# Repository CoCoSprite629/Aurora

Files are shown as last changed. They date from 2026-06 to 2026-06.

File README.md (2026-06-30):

# 🌌 Aurora

> 基于 ESP32 的桌面智能天气终端 ｜ IoT Desktop Smart Weather Display

**Aurora**（曙光女神）是一款基于 **ESP32** 的桌面智能物联网终端。通过 WiFi 联网获取实时天气、未来预报、NTP 网络时间与节日信息，将数据呈现在 **HMI 串口触摸屏**上，同时以 **WS2812B 可编程 LED** 的呼吸灯效反馈系统状态。整机配备 3D 打印外壳，适合作为桌面摆件、电子手工作品或物联网学习项目。

---






---

## 功能特性

- 🌤️ **实时天气显示** — 调用高德天气 API，获取当前温度、湿度、风力及天气状况
- 📅 **未来三日预报** — 滚动展示未来三天的日间/夜间天气与温度
- ⏰ **NTP 网络时间** — 自动同步微软 NTP 服务器（`time.windows.com`），无需手动校准
- 🎉 **节日提醒** — 每日自动查询当天节日/纪念日，展示在屏幕底部
- 💡 **智能 LED 反馈** — 根据 WiFi 状态与温度范围变换颜色与呼吸节奏
- 📟 **HMI 串口屏交互** — 通过 Serial2 自定义协议驱动触摸屏，支持配网输入
- 📊 **双进度条** — 一天已过进度 + 自定义倒计时进度条
- 🧵 **FreeRTOS 多任务调度** — 3 个任务跨 Core 0 / Core 1 高效协同
- 🖨️ **3D 打印外壳** — 提供完整 STL 模型，可自行打印装配

---

## 硬件清单

| 组件 | 型号/规格 | 数量 | 说明 |
|---|---|:----:|---|
| 主控 | ESP32 DOIT DevKit V1 | 1 | WiFi + 蓝牙双模 |
| LED | WS2812B 可编程灯珠 | 1 | 状态指示灯，GRB 色彩排列 |
| 触摸屏 | 陶晶驰 (TJC) HMI 串口屏 | 1 | 用户交互界面 |
| 电源 | 5V / Micro-USB | 1 | 供电 |
| 检测脚 | 外部传感器 / 按键 (可选) | 1 | GPIO 19 输入检测 |

### 引脚连接

| 功能 | ESP32 引脚 | 说明 |
|---|:---:|---|
| WS2812B 数据线 (DI) | **GPIO 18** | FastLED 驱动 |
| 串口屏 RX (Serial2) | **GPIO 16** | ESP32 ← 屏幕 |
| 串口屏 TX (Serial2) | **GPIO 17** | ESP32 → 屏幕 |
| 电源检测 / 外部输入 | **GPIO 19** | 高电平触发屏幕弹窗 |

> ⚠️ **注意：** ESP32 与串口屏通信**务必共地**，否则可能造成信息乱码。

---

## 项目结构

```
Aurora/
├── README.md                        # 项目说明（本文件）
├── ESP32_Project/                   # ESP32 PlatformIO 主工程
│   ├── platformio.ini               # PlatformIO 项目配置
│   ├── src/
│   │   ├── main.cpp                 # 主程序入口 + FreeRTOS 任务
│   │   ├── WiFi_init.cpp            # WiFi 连接与错误处理
│   │   ├── dataTransmit.cpp         # API 请求、NTP、HMI 发送
│   │   └── LED_Controller.cpp       # WS2812B 灯效控制
│   ├── include/
│   │   ├── WiFi_init.h              # WiFi 相关声明
│   │   ├── dataTransmit.h           # 数据获取/发送声明
│   │   └── LEDController.h          # LED 控制声明
│   ├── lib/                         # 项目私有库目录
│   └── test/                        # 单元测试目录
├── PCB_Files/                       # 立创 EDA 专业版工程
│   ├── 主控板.epro                   # 主控板 PCB
│   ├── 电源板.epro                   # 电源板 PCB
│   └── 连接板.epro                   # 连接板 PCB
├── UartHmi_Project/                 # 陶晶驰串口屏工程
│   ├── RainbowMedia.HMI             # HMI 工程主文件
│   ├── *.zi                         # 字库资源文件
│   └── 天气icons/                   # 天气图标素材
├── model/                           # 3D 打印外壳模型
│   ├── 屏幕外壳.stl
│   ├── 屏幕外壳盖板.stl
│   ├── 屏幕支架.stl
│   ├── 底座.stl
│   ├── 底座盖板.stl
│   └── 主控屏幕连接.stl
├── fonts/                           # 中文字体源文件
│   ├── 字由文艺黑.ttf
│   ├── 懒设计字由公益体.ttf
│   ├── 阿里妈妈数黑体 Bold.ttf
│   └── 阿里巴巴普惠体-B.ttf
├── icons/                           # 天气图标（备用）
└── info/                            # 项目规划 XMind 脑图
    ├── Aurora总规划.xmind
    ├── Aurora代码逻辑.xmind
    ├── Aurora主控文件结构.xmind
    └── Aurora灯效.xmind
```

---

## 系统架构

```
┌──────────────────────────────────────────────────┐
│                    Aurora                        │
│                                                  │
│  ┌──────────────┐    Serial2     ┌────────────┐  │
│  │  HMI 触摸屏  │◄──────────────►│  ESP32     │  │
│  │  (陶晶驰TJC) │   115200 bps   │  DOIT V1   │  │
│  └──────────────┘                │            │  │
│                                  │  WS2812B ◄─┼── GPIO 18
│  ┌──────────────────────────┐    │            │  │
│  │      互联网 API          │    │  Detec ◄───┼── GPIO 19
│  │                          │    └──────┬─────┘  │
│  │  • 高德天气 API          │           │ WiFi    │
│  │  • vore.top IP 定位     │◄──────────┘        │
│  │  • songzixian 节日查询  │                    │
│  │  • time.windows.com NTP │                    │
│  └──────────────────────────┘                   │
└──────────────────────────────────────────────────┘
```

### 数据流

```
HMI 屏幕 ──(配网信息)──► Serial2 ──► ESP32 ──(WiFi)──► 互联网 API
                                                         │
HMI 屏幕 ◄──(天气/时间)── Serial2 ◄── ESP32 ◄──(JSON)───┘
                                                         
WS2812B LED ◄── 呼吸灯效 ── LED_Controller() (Core 1)
```

---

## 快速上手

### 前置要求

| 工具 | 用途 |
|---|---|
| [Visual Studio Code](https://code.visualstudio.com/) | 代码编辑器 |
| [PlatformIO IDE 插件](https://platformio.org/install/ide?install=vscode) | ESP32 编译烧录 |
| [立创 EDA 专业版](https://pro.lceda.cn/) | PCB 工程查看/编辑 |
| [陶晶驰上位机 (USART HMI)](http://www.tjc1688.com/) | 串口屏工程导入/编辑 |
| Micro-USB 数据线 | 烧录与供电 |

### 编译烧录

```bash
# 1. 克隆仓库
git clone https://github.com/your-username/Aurora.git
cd Aurora/ESP32_Project

# 2. 修改高德 API Key（重要！）
# 编辑 src/dataTransmit.cpp 第 55 行
# 将 key 变量替换为你自己的高德开放平台 API Key
String key = "你的高德API Key";

# 3. （可选）修改高中倒计时参数
# 编辑 src/dataTransmit.cpp 第 1057-1059 行，调整入学与毕业日期

# 4. 用 VS Code 打开 ESP32_Project 目录，点击 PlatformIO: Upload
```

> 也可以在终端中使用 PlatformIO Core CLI：
> ```bash
> cd ESP32_Project
> pio run --target upload
> ```

### 首次配网

1. 设备上电后，HMI 屏幕自动进入主页，LED 呈**紫色呼吸**（等待配网状态）
2. 通过屏幕输入 WiFi SSID 与密码
3. 屏幕向 ESP32 发送 `SERIAL_INIT` 指令，ESP32 开始连接
4. 连接成功后，LED 切换为**青紫色循环**（正在获取天气）
5. 获取天气数据后，LED 切换为**温度对应颜色呼吸**（正常运行）

---

## 配置说明

### 必须修改的参数

| 参数 | 文件 | 行号 | 说明 |
|---|---|:----:|---|
| `key` | `dataTransmit.cpp` | L55 | 高德开放平台 API Key，**必须替换** |

### 可调参数

| 参数 | 文件 | 行号 | 默认值 | 说明 |
|---|---|:----:|---|---|
| `BRIGHT` | `LED_Controller.cpp` | L7 | `5` | LED 全局亮度 (0-255) |
| `LIGHT_PIN` | `LED_Controller.cpp` | L6 | `18` | WS2812B 数据引脚 |
| `POWER_DETEC` | `main.cpp` | L14 | `19` | 外部检测引脚 |
| `ntp_Sever` | `dataTransmit.cpp` | L68 | `time.windows.com` | NTP 时间服务器 |
| `gmt_Offset_sec` | `dataTransmit.cpp` | L70 | `3600 * 8` | 时区偏移（东八区） |
| 高中倒计时 | `dataTransmit.cpp` | L1057-1059 | 2023.9.1 → 2026.6.9 | 自定义倒计时参数 |

### LED 灯效颜色

| 温度范围 | 颜色 | RGB |
|---|---|-----|
| `> 30°C` 酷暑 | 🔴 红色 | `(255, 51, 0)` |
| `20 ~ 30°C` 较热 | 🟠 橙色 | `(255, 153, 51)` |
| `0 ~ 20°C` 适宜 | 🟣 紫色 | `(140, 99, 237)` |
| `-10 ~ 0°C` 冷 | 🔵 蓝色 | `(51, 153, 255)` |
| `< -10°C` 极寒 | ⚪ 白色 | `(255, 255, 255)` |

---

## 通信协议

### 串口屏幕指令（ESP32 → HMI）

屏幕与 ESP32 通过 **Serial2**（GPIO 16/17，115200 bps）通信。

| 指令格式 | 说明 | 示例 |
|---|---|---|
| `控件.属性=值\xff\xff\xff` | 控制屏幕控件 | `main.t1.txt="Mon·26/6/29"\xff\xff\xff` |
| `页面.图片.pic=N\xff\xff\xff` | 切换图片资源 | `main.p1.pic=7\xff\xff\xff` |
| `页面.进度条.val=N\xff\xff\xff` | 设置进度条 | `main.j0.val=75\xff\xff\xff` |
| `页面.检测.val=N\xff\xff\xff` | 触发检测动画 | `main.detection3.val=1\xff\xff\xff` |

### 串口屏幕指令（HMI → ESP32）

屏幕通过 `\r`（回车符）分隔的字符串向 ESP32 发送信号：

| 指令 | 后续参数 | 含义 |
|---|---|---|
| `SERIAL_INIT` | SSID `\r` Password | 主页配网（pageID = 1） |
| `WIFI_INFO` | SSID `\r` Password | WiFi 页面配网（pageID = 3） |

### HMI 页面结构

| 页面名 | 用途 | 主要控件 |
|---|---|---|
| `main` | 主页 | 时间 `t0`、日期 `t1`、城市 `t7`、天气 `t5`、温度 `t11`、湿度 `t10`、风力 `t9`、节日 `t4`、天气图标 `p1`、进度条 `j0`/`j1` |
| `WiFi` | 配网页面 | 连接状态 `error.val`、错误图标 `p0` |
| `MoreWeather` | 天气预报 | 今日详情 + 未来三天 `p3`/`p4`/`p5`、日期星期、温度风力 |

### API 接口

| 函数 | 请求 URL | 用途 |
|---|---|---|
| `get_ADcode()` | `https://api.vore.top/api/IPdata?ip=` | 获取 IP 对应行政区划编码 |
| `getTodayWeather()` | `https://restapi.amap.com/v3/weather/weatherInfo?city=ADcode&key=KEY&extensions=base` | 高德实时天气（base 模式） |
| `getFutureWeather()` | `https://restapi.amap.com/v3/weather/weatherInfo?city=ADcode&key=KEY&extensions=all` | 高德未来三日预报（all 模式） |
| `getFestival()` | `https://api.songzixian.com/api/holiday?dataSource=local_holiday&date=yyyy-MM-dd` | 查询当天节日 |

---

## LED 动画参考

| 状态 | 颜色 | 效果 | 触发条件 |
|---|---|---|---|
| 🔌 **等待配网** `SET_WIFI` | 紫色 `(204, 153, 255)` | 呼吸脉冲 (0→128→0) | 上电初始化 |
| 📡 **WiFi 连接中** `WIFI_IS_OK` | HSV 色相循环 (200→360) | 低亮度色相扫描 | 发起 WiFi 连接 / 等待天气 |
| ❌ **连接失败** `WIFI_FAIL` | 红色 `(255, 64, 64)` | 呼吸脉冲 (0→128→0) | 5 秒内未连接成功 |
| ✅ **天气就绪** `GOT_WEATHER` | 根据温度变化 (见上表) | 呼吸脉冲 (0→128→0) | 天气数据获取完成 |
| 🚨 **外部触发** | 屏幕弹窗 `detection3.val=1` | — | GPIO 19 高电平 |

---

## 软件架构

```
setup()
  ├── Serial.begin(115200)          // USB 调试串口
  ├── Serial2.begin(115200)         // HMI 屏幕串口
  ├── Serial2.onReceive(onDataRecv) // 注册串口中断回调
  ├── LED_Setup()                   // 初始化 WS2812B / FastLED
  ├── LED_Status = "SET_WIFI"       // 初始灯效状态
  └── xTaskCreatePinnedToCore × 3   // 创建 FreeRTOS 任务

┌─ Task1: getInfo() [Core 0, Priority 1] ─────────────────────┐
│  wifi == 1 → WiFi_Connect()                                  │
│  WiFiStatus == 1 → get_ADcode() → getTodayWeather()         │
│                  → todayWeatherTransmit() → getFestival()    │
│                  → festivalTransmit() → getFutureWeather()  │
│                  → futureWeatherTransmit() → delay(48s)      │
└──────────────────────────────────────────────────────────────┘

┌─ Task2: setNTPServer() [Core 1, Priority 1] ────────────────┐
│  WiFiStatus == 1 → setTime() → setTimeTransmit()  (每 1s)    │
│  digitalRead(POWER_DETEC) == HIGH → 触发检测弹窗             │
└──────────────────────────────────────────────────────────────┘

┌─ Task3: LEDControl() [Core 1, Priority 2] ──────────────────┐
│  LED_Controller() → 根据 LED_Status 执行对应灯效  (每 20ms)  │
└──────────────────────────────────────────────────────────────┘

Serial2 中断回调 (onDataRecv)
  解析屏幕指令 → 提取 SSID/Password → 置 wifi = 1
```

> `loop()` 函数为空 — 所有逻辑均由 FreeRTOS 调度。

---

## 依赖库

| 库 | 版本 | 用途 |
|----|---|---|
| [FastLED](https://github.com/FastLED/FastLED) | ^3.7.3 | WS2812B LED 驱动（GRB 色彩顺序） |
| [ArduinoJson](https://arduinojson.org/) | 6.20.0 | JSON 解析（天气/节日 API 响应） |
| WiFi (ESP32 内置) | — | WiFi 连接与 HTTP 请求 |
| FreeRTOS (ESP32 内置) | — | 多任务调度 |

---

## 开发环境

- **IDE**: VS Code + PlatformIO
- **开发板**: ESP32 DOIT DevKit V1 (`esp32doit-devkit-v1`)
- **分区方案**: `huge_app.csv`
- **框架**: Arduino for ESP32
- **串口速率**: 115200 bps (Serial + Serial2)

---

## 工程文件打开说明

### PCB 工程

`PCB_Files/` 目录下包含三块电路板的 PCB 设计文件：

| 文件 | 说明 |
|---|---|
| `主控板.epro` | ESP32 主控板 |
| `电源板.epro` | 电源管理板 |
| `连接板.epro` | 板间连接板 |

> 📐 **请使用[立创 EDA 专业版](https://pro.lceda.cn/)** 打开 `.epro` 格式的工程文件。立创 EDA 标准版无法识别此格式。

### 串口屏工程

`UartHmi_Project/` 目录包含陶晶驰 (TJC) 串口屏的完整工程：

| 文件 | 说明 |
|---|---|
| `RainbowMedia.HMI` | HMI 工程主文件（可编译/烧录） |
| `*.zi` | 字库资源文件（main, para, big 等多尺寸字库） |
| `天气icons/` | 天气图标素材（PNG 格式） |

> 🖥️ **请使用[陶晶驰 USART HMI 上位机](http://www.tjc1688.com/)** 导入 `.HMI` 工程文件。导入后可编辑界面、编译并烧录到屏幕。

### 3D 打印外壳

`model/` 目录下包含 6 个 STL 文件，构成完整外壳：

1. `屏幕外壳.stl` + `屏幕外壳盖板.stl` — 屏幕外壳组件
2. `屏幕支架.stl` — 屏幕固定支架
3. `底座.stl` + `底座盖板.stl` — 底座组件
4. `主控屏幕连接.stl` — 主控板与屏幕的连接件

> 建议使用 PETG 材质打印，0.2mm 层高，部分需支撑（具体视模型结构而定）。

---

## 使用场景

1. 将 ESP32 烧录固件后，装入 3D 打印外壳
2. 上电后，LED 呈紫色呼吸，等待配网
3. 在 HMI 触摸屏输入 WiFi 账号密码完成配网
4. 自动获取 IP 地理位置 → 查询当地天气 → 展示在主页
5. 左滑进入 `MoreWeather` 页面查看未来三日详细预报
6. LED 根据当前温度自动切换颜色呼吸
7. 每日自动展示当天节日/纪念日信息

---

## 项目历程

| 日期 | 里程碑 |
|---|---|
| 7.10 | RainbowTimer 的 Plus Ultra 版本正式立项，取名 **RainbowMedia** |
| 7.15 | 舍弃 LVGL 图形库，全面转向串口屏方案 |
| 7.22 | 正式更名为 **Aurora**（曙光女神），完成初步功能验证 |
| 8.22 | 3D 外壳建模完成，项目进入收尾阶段 |

---

## 开源协议

本项目采用 **GNU General Public License v2.0 (GPL 2.0)** 开源协议。

> 你可以自由地使用、修改和分发本项目，但衍生作品也必须以 GPL 2.0 协议开源。

详细信息请参阅 [LICENSE](https://www.gnu.org/licenses/old-licenses/gpl-2.0.html) 文件。

---

## 致谢

- [高德开放平台](https://lbs.amap.com/) — 天气数据 API
- [FastLED](https://github.com/FastLED/FastLED) — 强大的 LED 驱动库
- [ArduinoJson](https://arduinojson.org/) — 轻量级 JSON 解析
- [PlatformIO](https://platformio.org/) — 嵌入式开发生态

---

<p align="center">
  <sub>Made with ❤️ and ESP32</sub>
</p>

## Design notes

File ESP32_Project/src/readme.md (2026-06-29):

                ###Aurora大事记###

7.10  RainbowTimer的plus ultra版正式立项，取名RainbowMedia

7.15  RainbowMedia舍弃LVGL图形库转用串口屏方案

7.22  RainbowMedia正式更名为Aurora,并且完成初步验证

8.22  Aurora外壳建模完成，Aurora项目进入收尾阶段

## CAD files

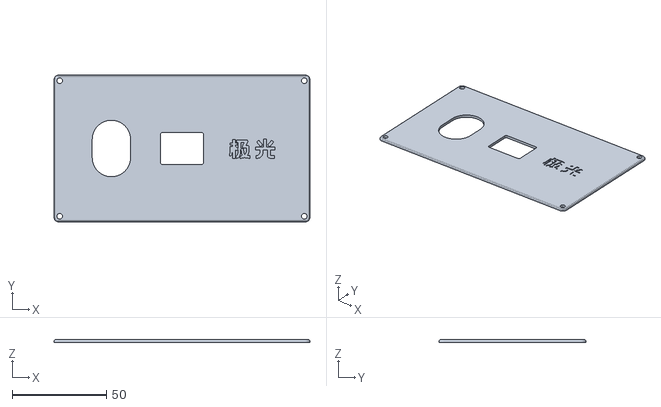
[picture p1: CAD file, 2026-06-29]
model/屏幕外壳盖板.stl
136.0 x 78.0 x 1.50

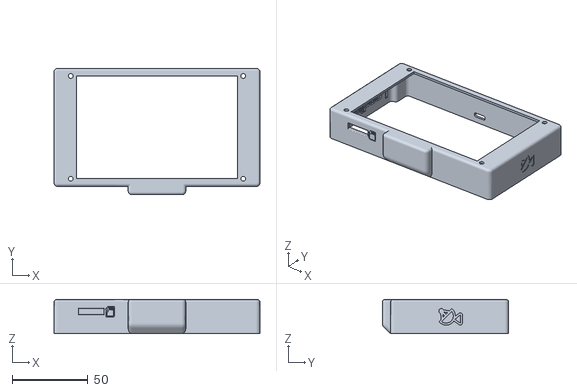
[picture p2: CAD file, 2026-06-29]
model/屏幕外壳.stl
136.0 x 83.5 x 22.5

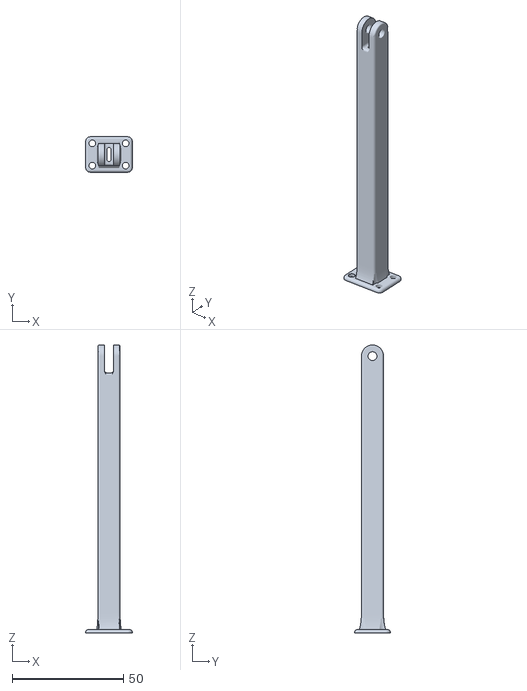
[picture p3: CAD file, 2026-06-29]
model/屏幕支架.stl
21.0 x 16.0 x 129.5

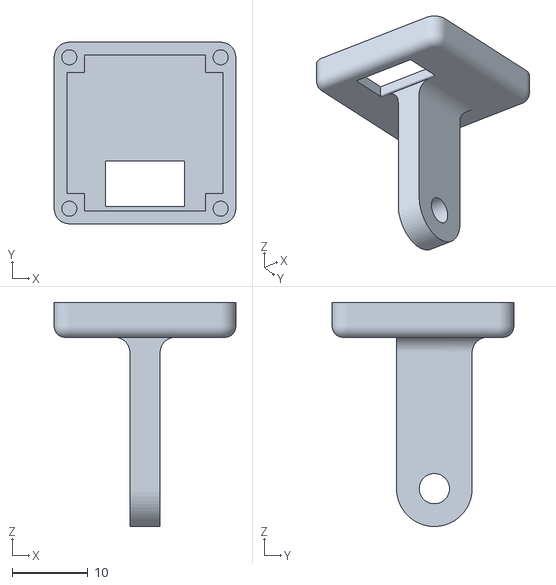
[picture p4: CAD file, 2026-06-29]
model/主控屏幕连接.stl
24.0 x 24.0 x 29.6

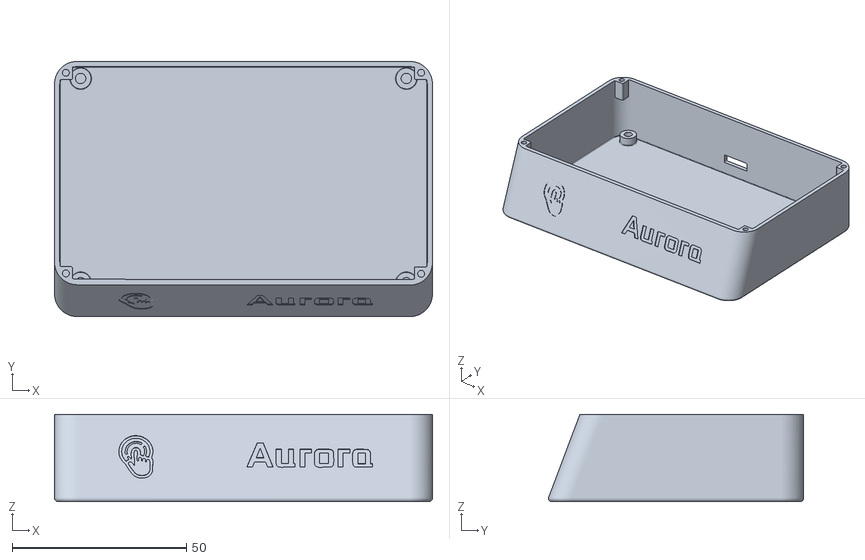
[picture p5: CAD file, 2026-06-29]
model/底座.stl
108.5 x 73.2 x 25.0

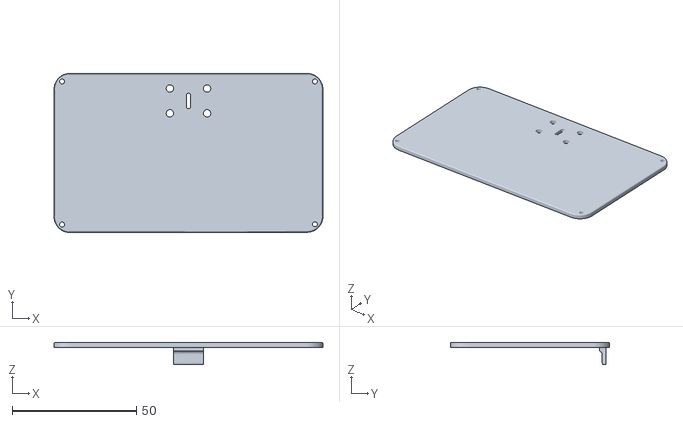
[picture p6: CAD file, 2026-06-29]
model/底座盖板.stl
108.5 x 64.2 x 9.00

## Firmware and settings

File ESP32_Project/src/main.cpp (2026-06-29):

/*
万物之宗
包含串口输入和处理函数
    api最终调用函数
    NTP时间服务更新函数
该项目采用FreeRTOS进行任务调度，loop函数不为最终单片机运行的总进程
*/

#include <Arduino.h>
#include <FastLED.h>
#include "WiFi_init.h"
#include "dataTransmit.h"
#include "LEDController.h"
#define POWER_DETEC 19
/*串口通信务必共地*/
/*定时器使用务必喂狗*/

TaskHandle_t Task1;
TaskHandle_t Task2;
TaskHandle_t Task3;
// 配置多进程

//hw_timer_t *timer  = NULL;

String recvData;
int wifi = 0;
int getIP = 1;
int postpone = 0;
int dect = 0;


void onDataRecv() // 串口中断回调函数
{
  if (Serial2.available() > 0)
  {
    recvData = Serial2.readStringUntil('\r');
    Serial.printf("%s", recvData);
    if (recvData == "SERIAL_INIT")
    {
      ssid = Serial2.readStringUntil('\r');
      passwords = Serial2.readStringUntil('\r');
      // Serial.printf("\nSSID: %s\nPassword: %s", ssid, passwords);
      wifi = 1;
      pageID = 1;
    }
    else if (recvData == "WIFI_INFO")
    {
      ssid = Serial2.readStringUntil('\r');
      passwords = Serial2.readStringUntil('\r');
      wifi = 1;
      pageID = 3;
      // Serial.printf("\nSSID: %s\nPassword: %s", ssid, passwords);
    }
  }
}

void LEDControl(void *pvParameters)
{
  while (1)
  {
    LED_Controller();
    delay(20);
  }
}


void getInfo(void *pvParameters)
{
  while (1)
  {
    if (wifi == 1)
    {
      WiFi_Connect();
      wifi = 0;
    }
    else if (wifi == 2)
    {
      Serial.printf("SSID: %s\nPassword: %s", ssid, passwords);
      WiFi_Connect();
    }

    if (WiFiStatus == 1)
    {
      delay(2000);
      if (getIP == 1)
      {
        get_ADcode();
      }
      getTodayWeather();
      todayWeatherTransmit();
      getFestival();
      festivalTransmit();
      delay(1000);
      getFutureWeather();
      futureWeatherTransmit();
      delay(48000);
    }
    delay(300);  //防止死循环看门狗超时
  }
}

void setNTPServer(void *pvParameters)
{
  while (1)
  {
    if (WiFiStatus == 1)
    {
      if (postpone == 0)
      {
        delay(2000);
        postpone = 1;
      }
      setTime();
      setTimeTransmit();
      delay(1000);
    }
    delay(200);
    if (digitalRead(POWER_DETEC) == HIGH && dect == 0)
    {
      Serial2.printf("main.detection3.val=1\xff\xff\xff");
      dect = 1;
    }
    if (digitalRead(POWER_DETEC) == LOW)
    {
      dect = 0;
    }
  }
}

void setup()
{
  Serial.begin(115200);
  Serial2.begin(115200);
  Serial2.onReceive(onDataRecv);
  LED_Setup();
  LED_Status = "SET_WIFI";

  /*
  timer = timerBegin(0, 80, true);  // 80分频，一次计数等于1us
  timerAttachInterrupt(timer, timerCallBack, true);  //边沿触发
  timerAlarmWrite(timer, 200000, true);
  timerAlarmEnable(timer);  //使能定时器
  */

  xTaskCreatePinnedToCore(
      getInfo, //配置进程运行主函数
      "Task1",  //进程名
      10000,    //设置堆栈大小
      NULL,     
      1,        //设置优先级
      &Task1,   //任务句柄
      0);       //在core 0运行
  delay(500);

  xTaskCreatePinnedToCore(
      setNTPServer,   
      "Task2", 
      10000,   
      NULL,    
      1,       
      &Task2,  
      1);      //在core 1运行
  delay(500);

  xTaskCreatePinnedToCore(
      LEDControl,   
      "Task3", 
      10000,   
      NULL,    
      2,       
      &Task3,  
      1);      //在core 1运行
  delay(500);
}

void loop()
{
  //任务使用FreeRTOS调度
}

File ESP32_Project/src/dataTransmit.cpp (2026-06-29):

/*
项目核心库
包含NTP时间获取
    api信息的爬取
    主控-串口屏通信
*/

#include <Arduino.h>
#include <WiFi.h>
#include <HTTPClient.h>
#include <ArduinoJson.h>
#include "WiFi_init.h"
#include "LEDController.h"
//#define debug

String result1; // 邮政编码
String result2; // 今日天气
String result3; // 未来天气
String result4;// 今日节日

String Location;
String province;
String city;
String weather;
String temperature;
String windPower;
String humidity;

String dayWeather1;
String nightWeather1;
String dayWeather2;
String nightWeather2;
String dayWeather3;
String nightWeather3;
String windPower1;
String windPower2;
String windPower3;

String festival;

String dat_week;
String time_;
String updateTime;
String allDate = "";
String formatMon;
String formatDay;
int passTime;
int seniorPassTime;
String week1, week2, week3;

String URL1 = "https://api.vore.top/api/IPdata?ip="; // 邮编获取
String URL2;                                         // 今日天气获取
String URL3;                                         // 天气预报获取
String URL4;
String key = "xxxxxxxxxxxxxxxxxxxxxxxxxxxxxxxxxx";

const char *location = "";
String dayTemperature1;
String nightTemperature1;
String dayTemperature2;
String nightTemperature2;
String dayTemperature3;
String nightTemperature3;
String updateTim;


/***********NTP时间同步配置***********/
const char *ntp_Sever = "time.windows.com"; // 微软服务器就是靠谱
// NTP服务器地址
const long gmt_Offset_sec = 3600 * 8;
// 时区，以中时区为基准，东八区为3600 * 8
const int daylightOffset_sec = 0;
// 不使用夏令时
/*********************************/

void get_ADcode()
{
    HTTPClient http1;
    // 初始化http
    http1.begin(URL1);
    // 发送请求
    int HttpCode1 = http1.GET();
    // 获取状态码
    while (1)
    {
        if (HttpCode1 > 0)
        {
            //Serial.println();
            // Serial.printf("httpCode:%d", HttpCode1);
            if (HttpCode1 == HTTP_CODE_OK)
            { // 200为成功接收
                result1 = http1.getString();
                // Serial.println(Result1);
                // Debug使用
                //  设置AruinoJson内存
                DynamicJsonDocument doc(1024);
                deserializeJson(doc, result1);
                // 将结果存入doc
                location = doc["adcode"]["a"];
                // city = doc["ipdata"]["info3"];  //获取城市(不带所属等级)
                Location = String(location);
                Serial.printf("Location ADCode: %s", Location);
                break;
            }
        }
        else
        {
            Serial.println("Get Failed");
            Serial.printf("Error Code: %d", HttpCode1);
            // LED_Status = "WIFI_FAIL";
        }
        delay(1000);
    }
    http1.end();
}

void getTodayWeather()
{
    HTTPClient http2;
    URL2 = "https://restapi.amap.com/v3/weather/weatherInfo?city=" +
        Location + "&key=" + key + "&extensions=base";
    // Serial.println(URL2);
    http2.begin(URL2);
    int HttpCode2 = http2.GET();
    if (HttpCode2 > 0)
    {
        Serial.println();
        // Serial.printf("httpCode:%d", HttpCode2);
        if (HttpCode2 == HTTP_CODE_OK)
        {
            result2 = http2.getString();
            // Serial.println(Result2);
            DynamicJsonDocument doc(1024);
            // 设置Ardeclarations]uinoJson内存
            deserializeJson(doc, result2);
            // 将结果存入doc
            const char* City = doc["lives"][0]["city"];                // 获取所在城市
            city = String(City);
            const char* Province = doc["lives"][0]["province"];        // 获取所在省份
            province = String(Province);
            const char* temp = doc["lives"][0]["temperature"];  // 获取温度
            temperature = String(temp);
            const char* temp1 = doc["lives"][0]["weather"]; // 获取天气
            weather = String(temp1);                        // 转换成String型供图标检测
            const char* temp2 = doc["lives"][0]["humidity"];        // 获取空气湿度
            humidity = String(temp2);
            const char* temp3 = doc["lives"][0]["windpower"];      // 获取当前风力大小
            windPower = String(temp3);
            Serial.printf("Today's temperature: %s", String(weather));
            Serial.printf("\nAir Humidity is: %s", String(humidity));
            Serial.printf("\nLocation: %s·%s", province, city);
        }
        else
        {
            Serial.println("GET failed");
            Serial.printf("Error Code: %d", HttpCode2);
            // LED_Status = "WIFI_FAIL";
        }
    }
    http2.end();
}


void getFutureWeather()
{
    HTTPClient http3;
    URL3 = "https://restapi.amap.com/v3/weather/weatherInfo?city=" +
        Location + "&key=" + key + "&extensions=all";
    #if (debug)
        Serial.printf("\nURL3: %s", URL3);
    #endif
    http3.begin(URL3);
    int HttpCode3 = http3.GET();
    if (HttpCode3 > 0)
    {
        Serial.println();
        // Serial.printf("httpCode:%d", HttpCode2);
        if (HttpCode3 == HTTP_CODE_OK)
        {
            result3 = http3.getString();
            #if (debug)
                Serial.println(result3);
            #endif
            DynamicJsonDocument doc(2048);
            // 设置Ardeclarations]uinoJson内存
            deserializeJson(doc, result3);
            // 将结果存入doc
            updateTim = doc["forecasts"][0]["reporttime"].as<String>();
            dayTemperature1 = doc["forecasts"][0]["casts"][1]["daytemp"].as<String>();          // 获取日间温度
            nightTemperature1 = doc["forecasts"][0]["casts"][1]["nighttemp"].as<String>();      // 获取夜间温度
            dayTemperature2 = doc["forecasts"][0]["casts"][2]["daytemp"].as<String>();          // 获取日间温度
            nightTemperature2 = doc["forecasts"][0]["casts"][2]["nighttemp"].as<String>();      // 获取夜间温度
            dayTemperature3 = doc["forecasts"][0]["casts"][3]["daytemp"].as<String>();          // 获取日间温度
            nightTemperature3 = doc["forecasts"][0]["casts"][3]["nighttemp"].as<String>();      // 获取夜间温度
            #if (debug)
                Serial.printf("Weather: %s", dayTemperature3.c_str());
            #endif
            dayWeather1 = doc["forecasts"][0]["casts"][1]["dayweather"].as<String>();   // 获取日间天气
            dayWeather2 = doc["forecasts"][0]["casts"][2]["dayweather"].as<String>();   // 获取日间天气
            dayWeather3 = doc["forecasts"][0]["casts"][3]["dayweather"].as<String>();   // 获取日间天气
            windPower1 = doc["forecasts"][0]["casts"][1]["daypower"].as<String>();
            windPower2 = doc["forecasts"][0]["casts"][2]["daypower"].as<String>();
            windPower3 = doc["forecasts"][0]["casts"][3]["daypower"].as<String>();
        }
        else
        {
            Serial.println("GET failed");
            Serial.printf("Error Code: %d", HttpCode3);
            // LED_Status = "WIFI_FAIL";
        }
    }
    //Serial.println("Ending");
    http3.end();
}
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

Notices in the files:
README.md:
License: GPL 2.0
